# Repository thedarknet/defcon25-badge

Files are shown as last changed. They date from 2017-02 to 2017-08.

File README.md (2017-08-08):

# defcon25-badge
Badge Related items for defcon 25

Assembly instructions are located here:

https://dcdark.net/2017/badge/index.html

-----
Installation of IDE:
Follow the following instructions (step by step):  

http://gnuarmeclipse.github.io/install/

	Notes: on Window's have gotten both Mars and Luna to work
	on linux i've only gotten luna to work (on ubuntu 16.04 LTS)

Once eclipse is set up here's what the debug config needs to look like, notes the 2 -f openocd scripts that must be configured.

For 2017 development we are using this nucleo board, while it is not the exact MCU we plan to use it is close and the one we want to use does not have a dev kit.

http://www.st.com/content/st_com/en/products/evaluation-tools/product-evaluation-tools/mcu-eval-tools/stm32-mcu-eval-tools/stm32-mcu-nucleo/nucleo-f302r8.html

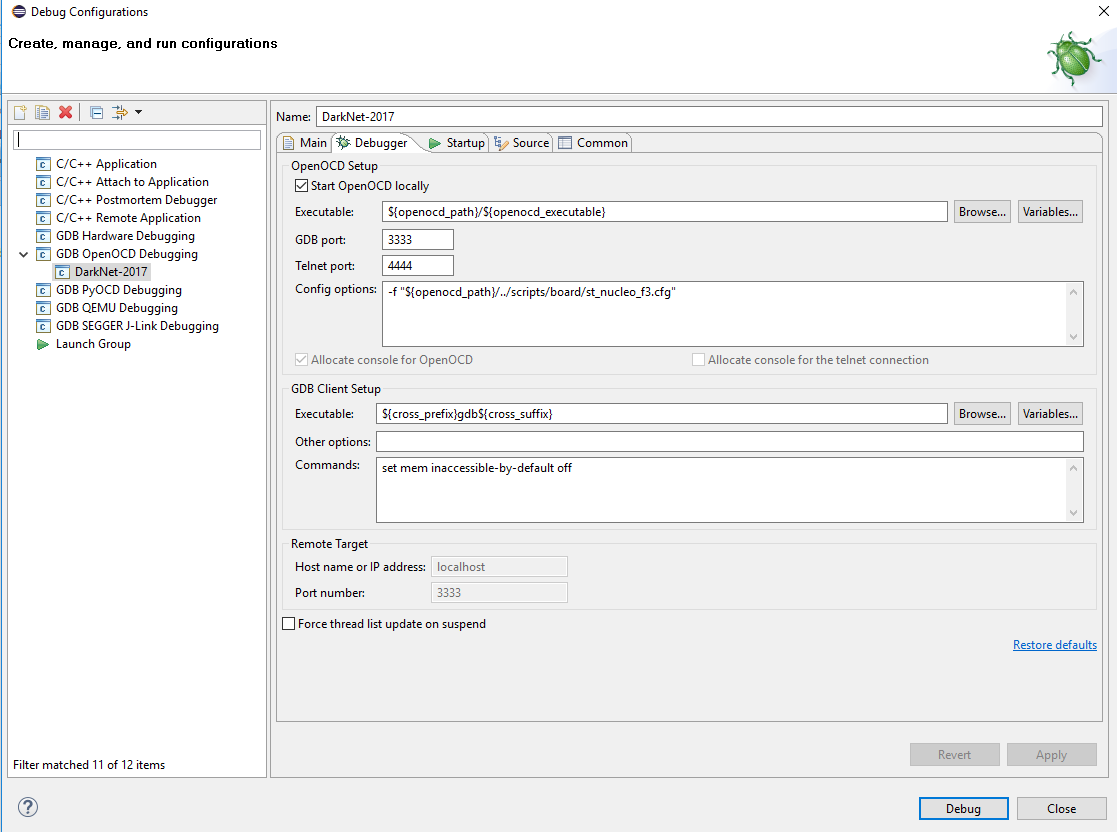
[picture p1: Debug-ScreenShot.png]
Debug Config


If you have the actual badge board you'll need debugging to look like this:

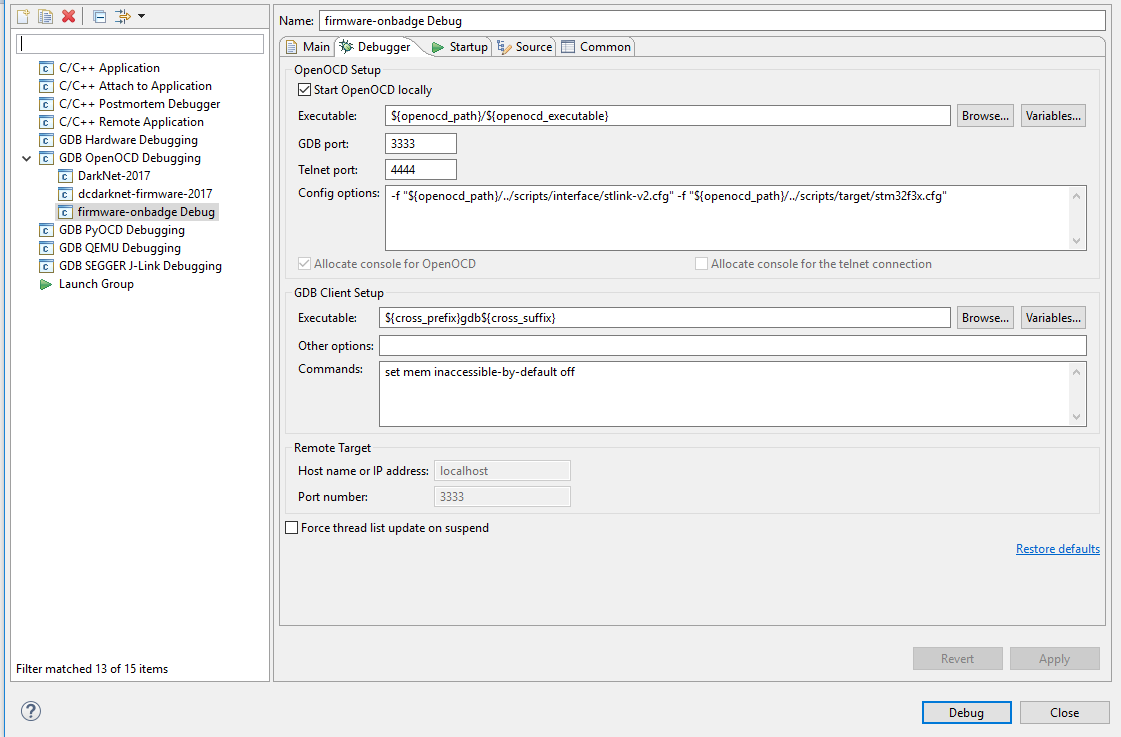
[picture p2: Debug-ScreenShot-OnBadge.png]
Debug Config


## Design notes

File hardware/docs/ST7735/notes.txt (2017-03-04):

SDA is infact: MOSI as the board is SPI not I2C

--https://webcache.googleusercontent.com/search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

https://github.com/XarkLabs/PDQ_GFX_Libs/blob/master/PDQ_ST7735/PDQ_ST7735.h line 513...that's the fastest avr can go but can the display go faster?

--1.44 seem to actually be IL19163C (not st7735)
https://luigidifraia.wordpress.com/2016/02/19/lcd-display-panels-casting-some-light-on-the-mess/
https://forum.pjrc.com/threads/25862-ILI9163C-128x128-TFT-driver
https://github.com/sumotoy/TFT_ILI9163C
http://www.ebay.co.uk/itm/111317541232?afsrc=1&rmvSB=true

https://forum.arduino.cc/index.php?topic=260605.135

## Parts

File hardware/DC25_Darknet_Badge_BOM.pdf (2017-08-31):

Part | Description | Vendor | Part number / link | Required Notes
Printed Circuit Board | OSH Park | https://oshpark.com/shared_projects/Shj2PfBl | 1 | Getting the boards made is one of the more expensive parts.
RFM69HCW 915Mhz +20dBm HopeRF Wireless Transceiver (RFM69HCW-915S2) | HopeRF | RFM69HCW-915S2 | 1
1.8 inch SPI Color TFT LCD Display ST7735S Module + Red PCB adapter | Amazon | B01LXWJ5O1 | 1 | A lot of places in China copy this module and sell it.
PkCell Lithium Polymer battery, LP803860 with JST connector | Adafruit | 2011 | 1 | We had these manufactured for the kit from PkCell, but Adafruit sells the same battery
JST Header PH Side 2 Pos 2MM | Digikey | 455-1719-ND | 1
SW1 | Apem Tactile Switches 7.8mm square tact | Mouser | MJTP1243 | 1
R24 | Xicon 270 Series 47 Ohm 1/8W Metal film resistor | Mouser | 270-47-RC | 1
LED11 | IR LED 940nm 100mA 210mW | Mouser | 782-TSAL6400 | 1
U3 | Vishay IR Receiver Module 2.5-5.5V 38kHz 45Deg 4000 bits/s | Digikey | TSOP2138 | 1 Wurth Electronics 2.54mm 4-pin Header | Mouser | 61300411121 | 1
| M3*14+6 Nylon Hex Standoff Spacer M3 Male x M3 Female 14mm | Amazon | SPC-NLB3MF/14-50 | 4 | You only need four, but the part is for a bag of 50
| M3 x 6mm Screws Nylon Round Head Phillips Drive Robot Light Bolts Plastic Black | Amazon | a16051100ux1000 | 4 | You only need four, but the part is for a bag of 100
| M3 Nylon Hex nuts Black | Amazon | a15070300ux0188 | 4 | You only need four, but the part is for a bag of 100
| .125"(3.2mm) x 12" x 12" Grey 2074 Acrylic Sheet | US Plastics | P-274 | 1
C1 | Multilayer Ceramic Capacitors MLCC - Johanson SMD/SMT 250volts 0.5pF ULTRA HIGH Q NPO | Mouser | 251R14S0R5BV4T | 1
C2 | Multilayer Ceramic Capacitors MLCC - Wurth Electronics SMD/SMT WCAP-CSGP 100000pF 0603 10% 10V MLCC | Mouser | 885012206020 | 1
C15 | Multilayer Ceramic Capacitors MLCC - Wurth Electronics SMD/SMT WCAP-CSGP 10000pF 0603 10% 16V MLCC | Mouser | 885012206040 | 1
C16 C17 C18 | Multilayer Ceramic Capacitors MLCC - AVX SMD/SMT 6.3V 4.7uF X5R 0603 20% Tol | Mouser | 06036D475MAT4A | 3
C19 C20 | Multilayer Ceramic Capacitors MLCC - AVX SMD/SMT 25V 47pF NP0 0603 10% Tol Auto | Mouser | 06033A470K4T2A | 2
C21 | Multilayer Ceramic Capacitors MLCC - Wurth Electronics SMD/SMT WCAP-CSGP1uF 0603 20% 10V MLCC | Mouser | 885012106010 | 1
C22 C23 C24 C25 | Multilayer Ceramic Capacitors MLCC - Wurth Electronics SMD/SMT WCAP-CSGP 47000pF 0603 10% 16V MLCC | Mouser | 885012206044 | 4
F1 | Bel Resettable Fuses - PPTC | Mouser | 0ZCJ0050FF2G | 1
L1 | Murata Ferrite Beads 0805 220 OHM | Mouser | BLM21PG221SN1D | 1
L2 | Bourns Fixed Inductors 10nH 5% MultiLayer High Frequency | Mouser | 652-CI160808-10NJ | 1
L3 | Bourns Fixed Inductors 4.7nH .3% MultiLayer High Frequency | Mouser | CI160808-4N7D | 1
LED12 LED13 | Lumex Standard LEDs - SMD Super Green, 565nm 2.2V, 20mcd | Mouser | SML-LX0603SGW-TR | 2
R1 thru R10 | Vishay Thick Film Resistors - SMD 1/4watt 47ohms 5% | Mouser | CRCW120647R0JNEA | 10
R11 thru R21 R31 R32 KOA Speer Thick Film Resistors - SMD 1/10W 5.1K OHM 5% | Mouser | RK73B1JTTDD512J | 13
R22 R30 R33 R34 R35 KOA Speer Thick Film Resistors - SMD 1/10W 2K OHM 5% | Mouser | RK73B1JTTDD202J | 5
R23 | Panasonic Thick Film Resistors - SMD 0603 470ohms 5% AEC-Q200 | Mouser | ERJ-3GEYJ471V | 1
R25 | Vishay Thick Film Resistors - SMD 1/10watt 10Kohms 1% | Mouser | CRCW060310K0FKEA | 1
R26 R27 | KOA Speer Thick Film Resistors - SMD 1/10W 27 OHM 5% | Mouser | RK73B1JTTDD270J | 2
R28 | KOA Speer Thick Film Resistors - SMD 1/10watts 68ohms 1% | Mouser | RK73H1JTTD68R0F | 1
| ARM Microcontrollers - STMicroelectronics MCU 32-Bit ARM Cortex M4 72MHz 128kB MCU FPU | Mouser | STM32F302RBT6 | 1
ANT | Johanson Antennas 915MHz ANTENNA | Mouser | 0915AT43A0026E | 1
U1 | ROHM Semiconductor LDO Voltage Regulators 1ch 500mA CMOS LDO Regulator | Mouser | BU33SD5WG-TR | 1
U2 | Microchip Battery Management Li-Ion/Li-Poly Charg Mgnt 4.5V Vreg out | Mouser | MCP73831T-5ACI/OT | 1
Y1 | Murata Resonators 8.000MHZ .5% CHIP RESONATOR | Mouser | CSTCE8M00G52-R0 | 1
LED1 thru LED10 | OSRAM LED YELLOW CLEAR 2SMD 222.5mcd 2V 20mA | Mouser | 720-LYT776Q2T126Z | 10 | Can be substituted with 720-LYT776S1T126Z

Note, this kit was designed to have most the surface mount parts assembled by pick and place. While it is

possible build the kit yourself, and solder everything by hand, it is more difficult than the kit sold at DEF CON.

However similar techniques can be used to hand solder, but extra parts should be ordered in anticipation of

small parts getting lost forever. To save on costs, I would also suggest working with other darknet agents to

do a group order and take advantage of price breaks.

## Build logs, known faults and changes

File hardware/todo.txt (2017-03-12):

TODO:
* schema:
* [DONE]: need to add sampling pins for touch to capacitor
* [DONE]: Remove capacitors from touch 
* [DONE]: add SD card NSS

4 layer ~$10 per board
2 layer ~5 per board

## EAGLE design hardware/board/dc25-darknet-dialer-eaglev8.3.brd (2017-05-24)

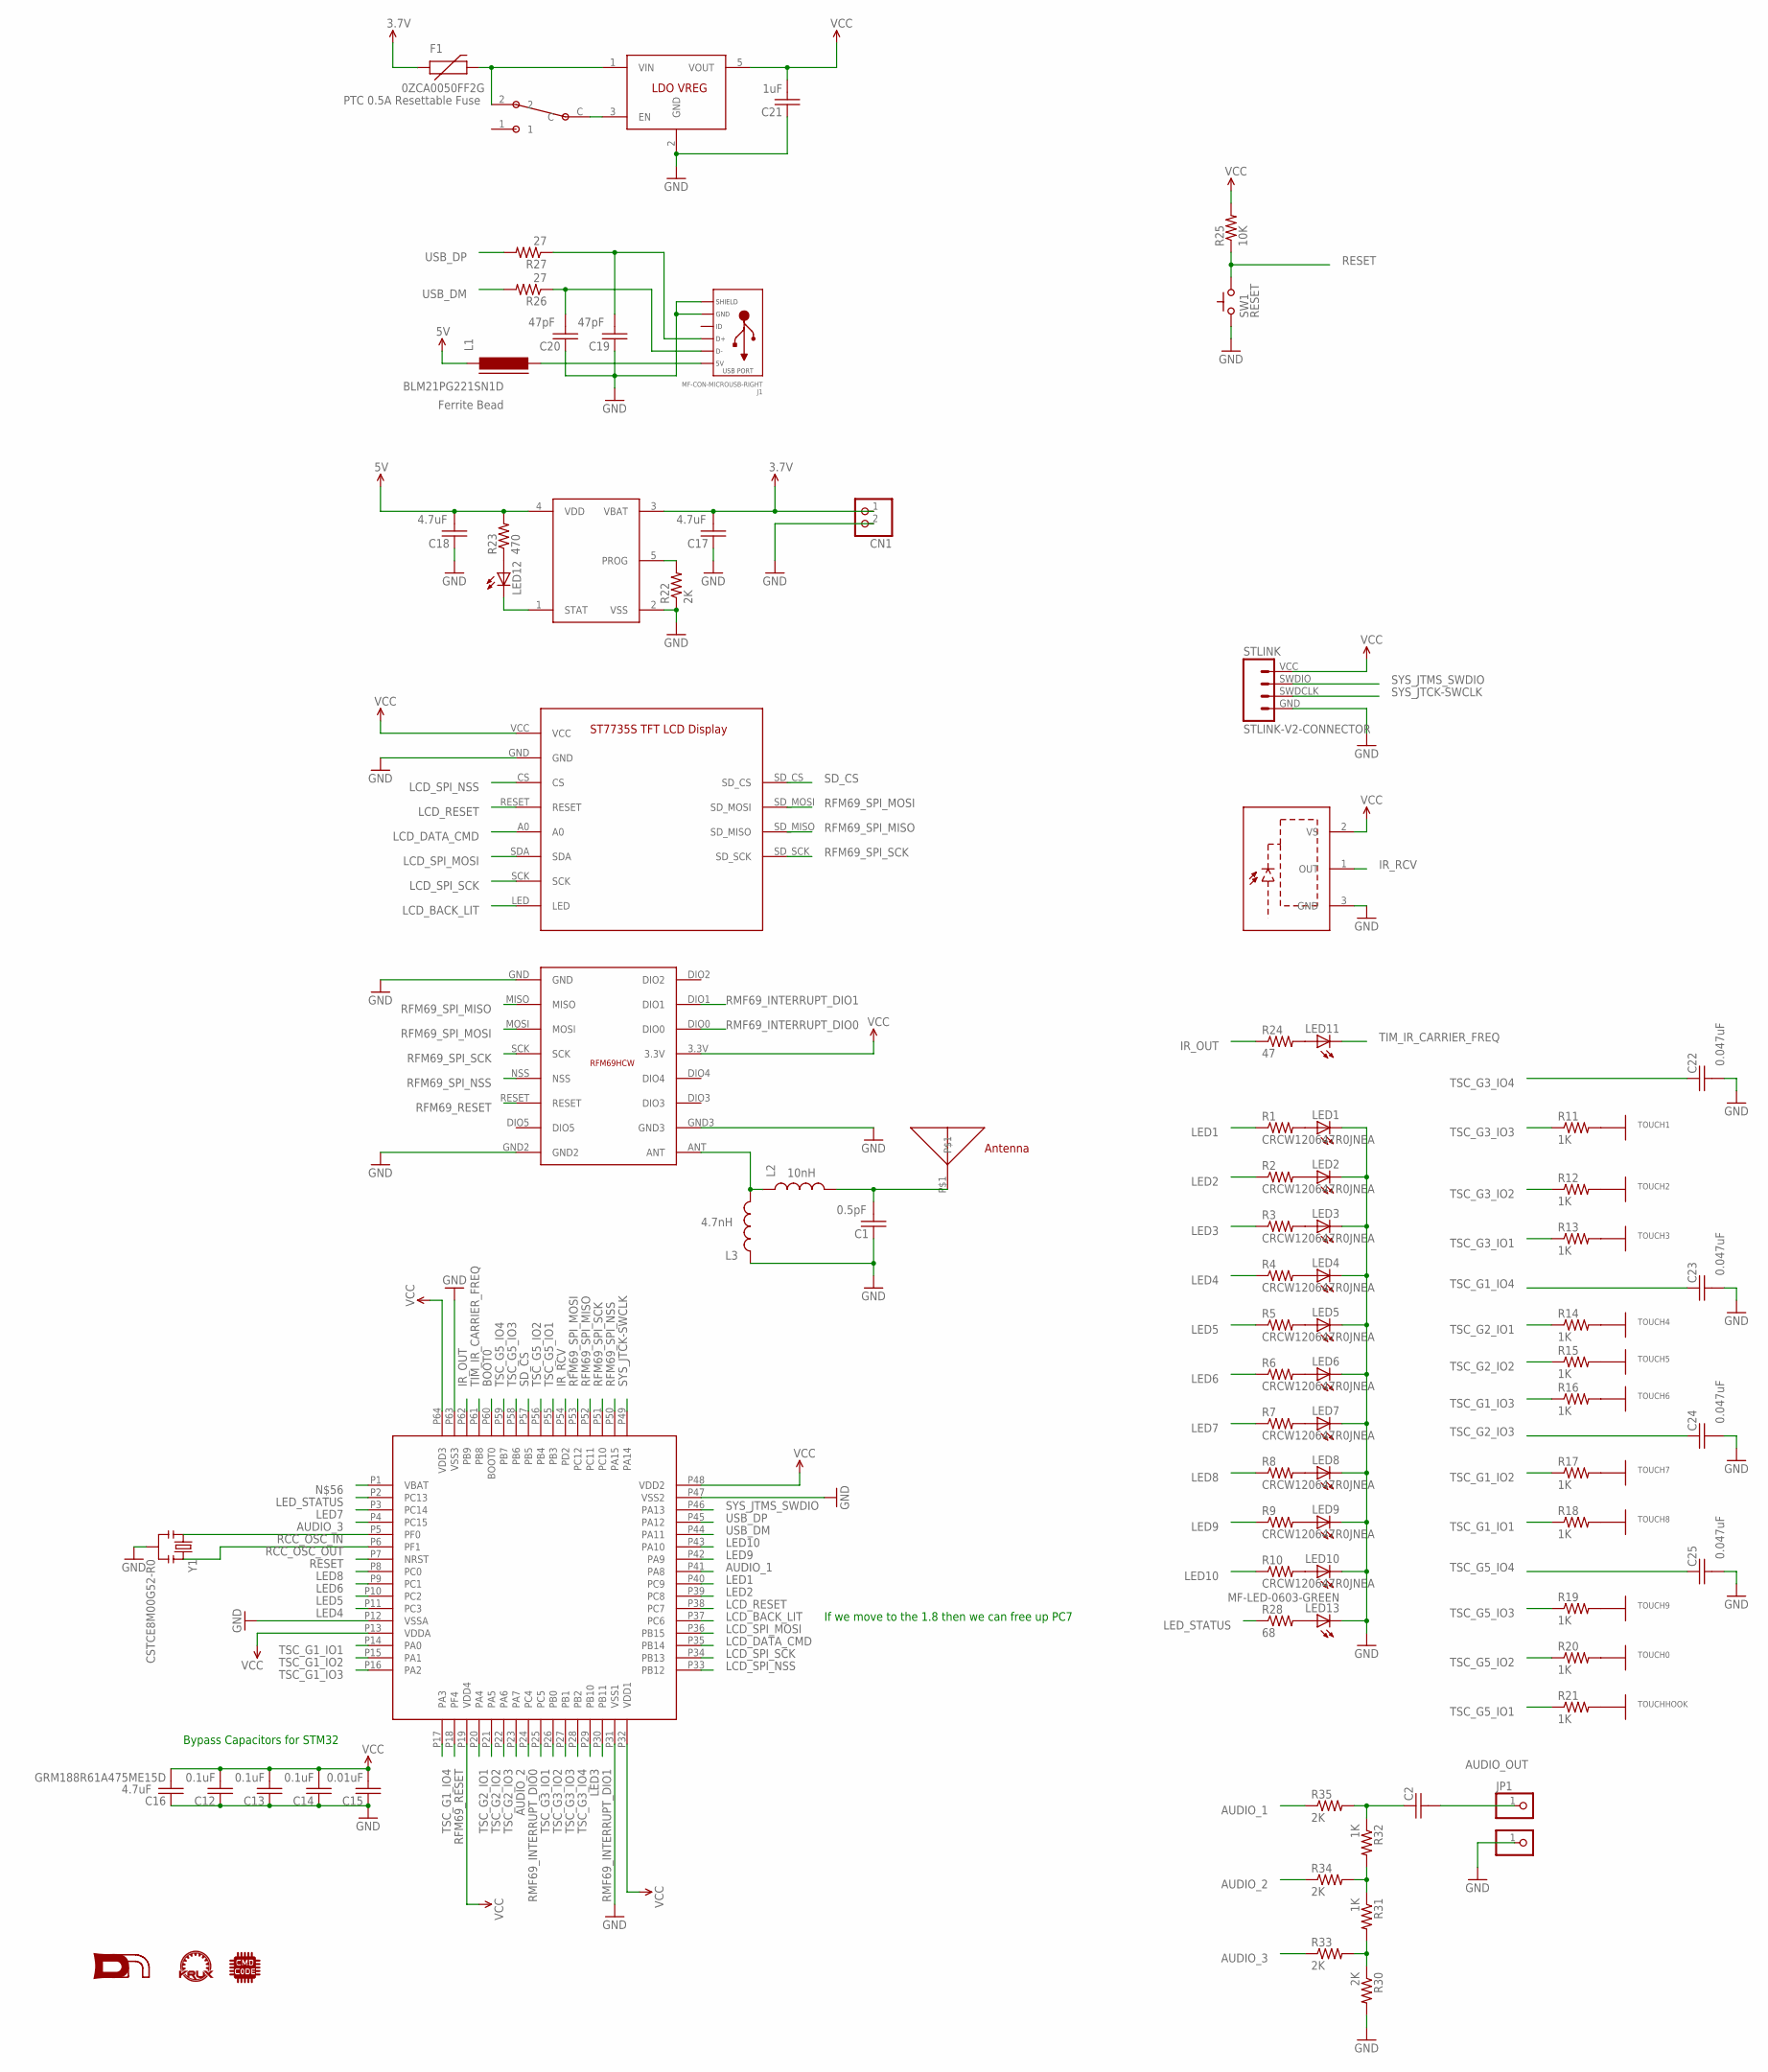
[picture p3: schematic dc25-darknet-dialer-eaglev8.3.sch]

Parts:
C1: 251R14S0R5BV4T; C0603
C2: GRM188C80G106ME47D; C0603
C12, C13, C14: 0.1uF; C0603
C15: 0.01uF; C0603
C16, C17, C18: GRM188R61A475ME15D; C0603
C19, C20: C0603C470J3GACTU; C0603
C21: 1uF; C0603
C22, C23, C24, C25: C0603C473J3RACAUTO; C0603
CN1: JST_2PIN-THM-RA; JST-PH-2-THM-RA
F1: 0ZCA0050FF2G; PTC-1206
J1: MF-CON-MICROUSB-RIGHT; MICROUSB-RIGHT
JP1, JP2: PINHD-1X1CB; 1X01-CLEANBIG
L1: BLM21PG221SN1D; FB603
L2: CI160808-10NJ; 0603
L3: CI160808-4N7D; 0603
LED1, LED2, LED3, LED4, LED5, LED6, LED7, LED8, LED9, LED10: LEDREVERSEMOUNT_NOPASTE; GULLWING_LED_NOPASTE
LED11: LED5MM
LED12, LED13: MF-LED-0603-GREEN; LED-0603
R1, R2, R3, R4, R5, R6, R7, R8, R9, R10: CRCW120647R0JNEA; 1206
R11, R12, R13, R14, R15, R16, R17, R18, R19, R20, R21, R31, R32: 1K; 0603-RES
R22, R30, R33, R34, R35: 2K; 0603-RES
R23: 470; 0603-RES
R24: 47; 0207/7
R25: 10K; 0603-RES
R26, R27: 27; 0603-RES
R28: 68; 0603-RES
STLINK: STLINK-V2-CONNECTOR; 1X04
SW1: RESET; TACTILE-2PIN-NARROW
TOUCH0: CAP_TOUCH0; CAP_TOUCH_PAD_0
TOUCH1: CAP_TOUCH1; CAP_TOUCH_PAD_1
TOUCH2: CAP_TOUCH2; CAP_TOUCH_PAD_2
TOUCH3: CAP_TOUCH3; CAP_TOUCH_PAD_3
TOUCH4: CAP_TOUCH4; CAP_TOUCH_PAD_4
TOUCH5: CAP_TOUCH5; CAP_TOUCH_PAD_5
TOUCH6: CAP_TOUCH6; CAP_TOUCH_PAD_6
TOUCH7: CAP_TOUCH7; CAP_TOUCH_PAD_7
TOUCH8: CAP_TOUCH8; CAP_TOUCH_PAD_8
TOUCH9: CAP_TOUCH9; CAP_TOUCH_PAD_9
TOUCHHOOK: CAP_TOUCHHOOK; CAP_TOUCH_PAD_HOOK
U1: BU33SD5WG-TR; SOT23-5
U2: MCP73831T-5ACI/OT; SOT23-5
U3: SOP22FLAT; IR-MODULE_FLAT
U$1: DN_LOGODC25; DARKNET_LOGO_DC25
U$2: STM32F302RBT6; LQFP64
U$11: SWITCH_SPDT; SPDT_SSAJ120100
U$12: KRUX_LOGO
U$15: RFM69HCWRFM69HCWSMDNOPASTE; 16PIN-PCB-SMD-NOPASTE
U$21: 0915AT43A0026E; CHIP_ANTENNA_1.8X8MM
U$22: ST7735S_LCD_MODULE; ST7735S_LCD_DISPLAY
U$23: CMD_C0DE_LOGO
Y1: CSTCE8M00G52-R0; RESONATOR-SMD

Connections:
ANT: L2.1, L3.2, U$15.ANT
AUDIO_1: R35.1, U$2.P41 (PA8)
AUDIO_2: R34.1, U$2.P23 (PA7)
AUDIO_3: R33.1, U$2.P4 (PC15)
AUDIO_OUT: C2.2, JP1.1
BOOT0: U$2.P60 (BOOT0)
GND: C1.1, C12.1, C13.1, C14.1, C15.1, C16.1, C17.1, C18.1, C19.1, C20.1, C21.1, C22.2, C23.2, C24.2, C25.2, CN1.2 (1), J1.5 (GND), J1.S1 (SLD), J1.S2 (SLD), J1.S3 (SLD), J1.S4 (SLD), J1.S5 (SLD), J1.S6 (SLD), JP2.1, L3.1, LED1.C, LED2.C, LED3.C, LED4.C, LED5.C, LED6.C, LED7.C, LED8.C, LED9.C, LED10.C, LED13.C, R22.1, R30.2, STLINK.GND, SW1.P$2 (C), U1.2 (GND), U2.2 (VSS), U3.3 (GND), U$2.P12 (VSSA), U$2.P31 (VSS1), U$2.P47 (VSS2), U$2.P63 (VSS3), U$15.GND, U$15.GND2, U$15.GND3, U$22.GND, Y1.2
IR_OUT: R24.1, U$2.P62 (PB9)
IR_RCV: U3.1 (OUT), U$2.P54 (PD2)
LCD_BACK_LIT: U$2.P37 (PC6), U$22.LED
LCD_DATA_CMD: U$2.P35 (PB14), U$22.A0
LCD_RESET: U$2.P38 (PC7), U$22.RESET
LCD_SPI_MOSI: U$2.P36 (PB15), U$22.SDA
LCD_SPI_NSS: U$2.P33 (PB12), U$22.CS
LCD_SPI_SCK: U$2.P34 (PB13), U$22.SCK
LED1: R1.1, U$2.P40 (PC9)
LED2: R2.1, U$2.P39 (PC8)
LED3: R3.1, U$2.P29 (PB10)
LED4: R4.1, U$2.P11 (PC3)
LED5: R5.1, U$2.P10 (PC2)
LED6: R6.1, U$2.P9 (PC1)
LED7: R7.1, U$2.P3 (PC14)
LED8: R8.1, U$2.P8 (PC0)
LED9: R9.1, U$2.P42 (PA9)
LED10: R10.1, U$2.P43 (PA10)
LED_STATUS: R28.1, U$2.P2 (PC13)
unnamed: R11.2, TOUCH1.PAD
unnamed: R12.2, TOUCH2.PAD
unnamed: R13.2, TOUCH3.PAD
unnamed: R14.2, TOUCH4.PAD
unnamed: R15.2, TOUCH5.PAD
unnamed: R16.2, TOUCH6.PAD
unnamed: R17.2, TOUCH7.PAD
unnamed: R18.2, TOUCH8.PAD
unnamed: R19.2, TOUCH9.PAD
unnamed: R20.2, TOUCH0.PAD
unnamed: R21.2, TOUCHHOOK.P$1
unnamed: LED1.A, R1.2
unnamed: LED2.A, R2.2
unnamed: LED3.A, R3.2
unnamed: LED4.A, R4.2
unnamed: LED5.A, R5.2
unnamed: LED6.A, R6.2
unnamed: LED7.A, R7.2
unnamed: LED8.A, R8.2
unnamed: LED9.A, R9.2
unnamed: LED10.A, R10.2
unnamed: R22.2, U2.5 (PROG)
unnamed: LED11.A, R24.2
unnamed: LED12.A, R23.1
unnamed: LED12.C, U2.1 (STAT)
unnamed: C19.2, J1.3 (D+), R27.1
unnamed: C20.2, J1.2 (D-), R26.1
unnamed: J1.1 (5V), L1.2
unnamed: LED13.A, R28.2
unnamed: F1.2, U1.1 (VIN), U$11.2
unnamed: C1.2, L2.2, U$21.P$1
unnamed: U1.3 (EN), U$11.C
unnamed: C2.1, R32.1, R35.2
unnamed: R31.1, R32.2, R34.2
unnamed: R30.1, R31.2, R33.2
RCC_OSC_IN: U$2.P5 (PF0), Y1.1
RCC_OSC_OUT: U$2.P6 (PF1), Y1.3
RESET: R25.1, SW1.P$1 (A), U$2.P7 (NRST)
RFM69_RESET: U$2.P18 (PF4), U$15.RESET
RFM69_SPI_MISO: U$2.P52 (PC11), U$15.MISO, U$22.SD_MISO
RFM69_SPI_MOSI: U$2.P53 (PC12), U$15.MOSI, U$22.SD_MOSI
RFM69_SPI_NSS: U$2.P50 (PA15), U$15.NSS
RFM69_SPI_SCK: U$2.P51 (PC10), U$15.SCK, U$22.SD_SCK
RMF69_INTERRUPT_DIO0: U$2.P24 (PC4), U$15.DIO0
RMF69_INTERRUPT_DIO1: U$2.P30 (PB11), U$15.DIO1
SD_CS: U$2.P57 (PB5), U$22.SD_CS
SYS_JTCK-SWCLK: STLINK.SWDCLK, U$2.P49 (PA14)
SYS_JTMS_SWDIO: STLINK.SWDIO, U$2.P46 (PA13)
TIM_IR_CARRIER_FREQ: LED11.K (C), U$2.P61 (PB8)
TSC_G1_IO1: R18.1, U$2.P14 (PA0)
TSC_G1_IO2: R17.1, U$2.P15 (PA1)
TSC_G1_IO3: R16.1, U$2.P16 (PA2)
TSC_G1_IO4: C23.1, U$2.P17 (PA3)
TSC_G2_IO1: R14.1, U$2.P20 (PA4)
TSC_G2_IO2: R15.1, U$2.P21 (PA5)
TSC_G2_IO3: C24.1, U$2.P22 (PA6)
TSC_G3_IO1: R13.1, U$2.P25 (PC5)
TSC_G3_IO2: R12.1, U$2.P26 (PB0)
TSC_G3_IO3: R11.1, U$2.P27 (PB1)
TSC_G3_IO4: C22.1, U$2.P28 (PB2)
TSC_G5_IO1: R21.1, U$2.P55 (PB3)
TSC_G5_IO2: R20.1, U$2.P56 (PB4)
TSC_G5_IO3: R19.1, U$2.P58 (PB6)
TSC_G5_IO4: C25.1, U$2.P59 (PB7)
USB_DM: R26.2, U$2.P44 (PA11)
USB_DP: R27.2, U$2.P45 (PA12)
VCC: C12.2, C13.2, C14.2, C15.2, C16.2, C21.2, R25.2, STLINK.VCC, U1.5 (VOUT), U3.2 (VS), U$2.P13 (VDDA), U$2.P19 (VDD4), U$2.P32 (VDD1), U$2.P48 (VDD2), U$2.P64 (VDD3), U$15.3.3V, U$22.VCC
VCC0: C18.2, L1.1, R23.2, U2.4 (VDD)
VCC1: C17.2, CN1.1 (2), F1.1, U2.3 (VBAT)

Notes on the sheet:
If we move to the 1.8 then we can free up PC7
Bypass Capacitors for STM32
0.5pF
4.7uF
47pF
0.047uF
PTC 0.5A Resettable Fuse
Ferrite Bead
10nH
4.7nH

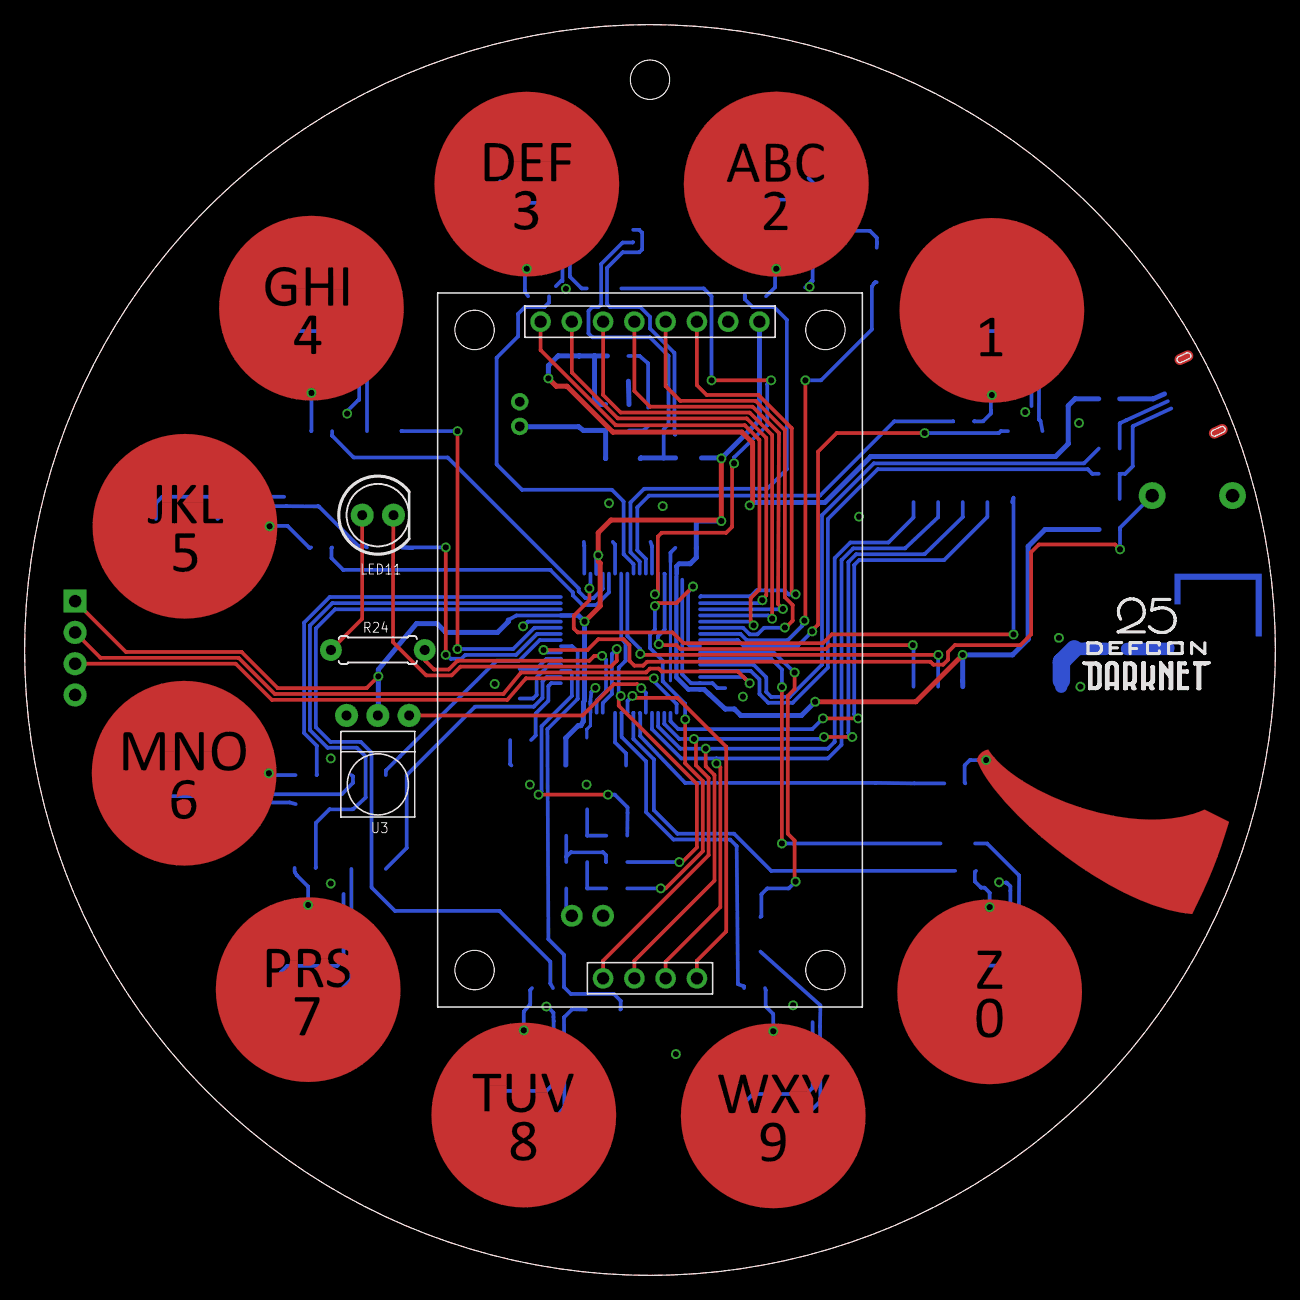
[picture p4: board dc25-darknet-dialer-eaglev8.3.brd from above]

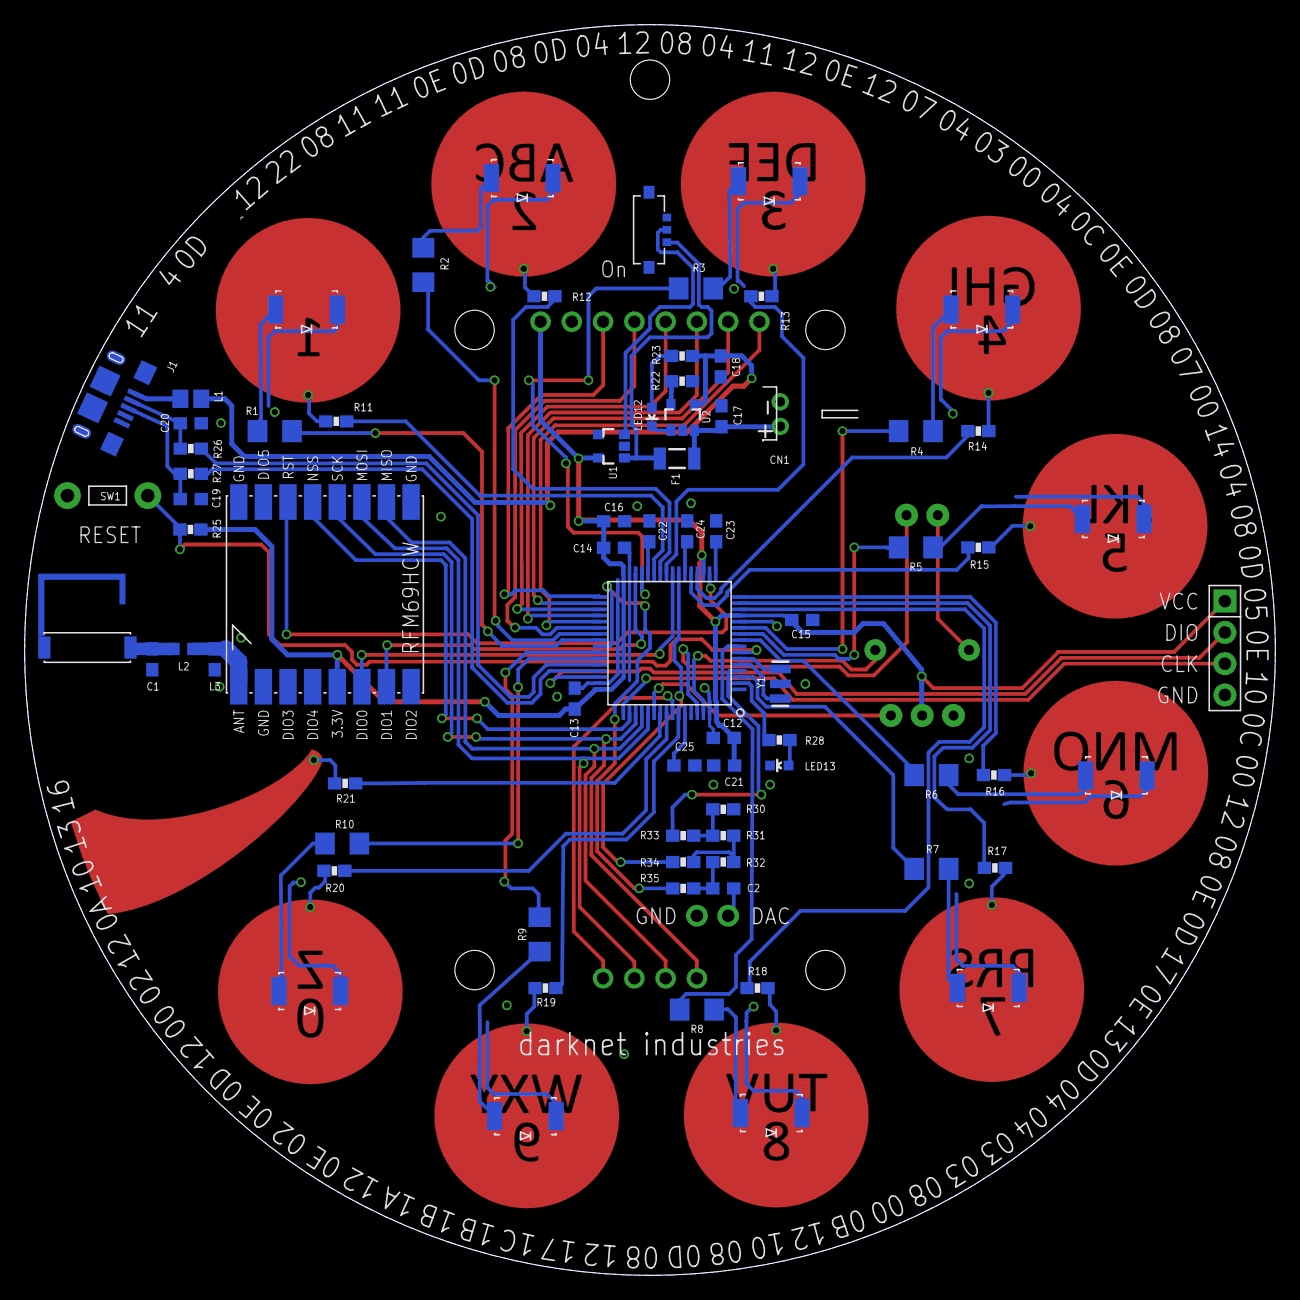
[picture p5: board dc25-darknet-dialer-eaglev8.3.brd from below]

Board: 2 copper layers, 101.6 x 101.6 mm, 96 parts (78 on the bottom side), 94 nets.

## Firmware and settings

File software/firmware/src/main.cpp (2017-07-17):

/**
 ******************************************************************************
 * File Name          : main.c
 * Description        : Main program body
 ******************************************************************************
 *
 * Copyright (c) 2017 STMicroelectronics International N.V.
 * All rights reserved.
 *
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
 ******************************************************************************
 */
/* Includes ------------------------------------------------------------------*/
#include "main.h"
#include "stm32f3xx_hal.h"
#include "dma.h"
#include "spi.h"
#include "tim.h"
#include "tsc.h"
#include "usb_device.h"
#include "gpio.h"

/* USER CODE BEGIN Includes */
#include "badge/dcdarknet_app.h"
#include "badge/logger.h"
#include "badge/ir.h"

/* USER CODE END Includes */


/* USER CODE BEGIN PV */
DCDarkNetApp DCDarkNet;
darknet::STM32Logger stm32DLogger(darknet::LOG_DEBUG_LEVEL);
darknet::STM32Logger stm32ILogger(darknet::LOG_INFO_LEVEL);
darknet::STM32Logger stm32ELogger(darknet::LOG_ERROR_LEVEL);

/* USER CODE END PV */

void SystemClock_Config(void);
void Error_Handler(void);

/* USER CODE BEGIN PFP */

/* USER CODE END PFP */

int main(void) {

	/* USER CODE BEGIN 1 */
	darknet::LogManager::get().addLogger(darknet::DEBUG_LOGGER_ID, &stm32DLogger);
	darknet::LogManager::get().addLogger(darknet::INFO_LOGGER_ID, &stm32ILogger);
	darknet::LogManager::get().addLogger(darknet::ERROR_LOGGER_ID, &stm32ELogger);
	/* USER CODE END 1 */

	/* MCU Configuration----------------------------------------------------------*/

	/* Reset of all peripherals, Initializes the Flash interface and the Systick. */
	HAL_Init();

	/* Configure the system clock */
	SystemClock_Config();

	/* Initialize all configured peripherals */
	MX_GPIO_Init();
	MX_DMA_Init();
	MX_SPI2_Init();
	MX_TIM16_Init();
	MX_TSC_Init();
	//MX_USB_DEVICE_Init();
	//comment if working on dev board
	MX_SPI3_Init();
	IRInit();

#if 0
	uint32_t t = 0;
	IRStartRx();
	while (t==0) {
		t = IRBytesAvailable();
	}
	//IRStartRx();
	char *p = (char *)IRGetBuff();
	INFOMSG(p);
#elif 0
	uint8_t b[5] = {0};
	IRTxBuff(&b[0],5);
#endif

	/* USER CODE BEGIN 2 */
	uint32_t initRet = DCDarkNet.init();
	if ((initRet & DCDarkNetApp::COMPONENTS_ITEMS::LCD) == 0) {
		// LCD did not initialize so we'll let the agent know via LED
		while (1) {
			HAL_GPIO_WritePin(LED_STATUS_GPIO_Port, LED_STATUS_Pin, GPIO_PIN_SET);
			HAL_Delay(200);
			HAL_GPIO_WritePin(LED_STATUS_GPIO_Port, LED_STATUS_Pin, GPIO_PIN_RESET);
			HAL_Delay(400);
		}
	}
	/* USER CODE END 2 */

	/* Infinite loop */
	/* USER CODE BEGIN WHILE */
	while (1) {
		/* USER CODE END WHILE */
		DCDarkNet.run();
		/* USER CODE BEGIN 3 */

	}
	/* USER CODE END 3 */

}

/** System Clock Configuration
 */
void SystemClock_Config(void) {

	RCC_OscInitTypeDef RCC_OscInitStruct;
	RCC_ClkInitTypeDef RCC_ClkInitStruct;
	RCC_PeriphCLKInitTypeDef PeriphClkInit;

	/**Initializes the CPU, AHB and APB busses clocks
	 */
	RCC_OscInitStruct.OscillatorType = RCC_OSCILLATORTYPE_HSE;
	RCC_OscInitStruct.HSEState = RCC_HSE_ON;
	RCC_OscInitStruct.HSEPredivValue = RCC_HSE_PREDIV_DIV1;
	RCC_OscInitStruct.PLL.PLLState = RCC_PLL_ON;
	RCC_OscInitStruct.PLL.PLLSource = RCC_PLLSOURCE_HSE;
	RCC_OscInitStruct.PLL.PLLMUL = RCC_PLL_MUL6;
	if (HAL_RCC_OscConfig(&RCC_OscInitStruct) != HAL_OK) {
		Error_Handler();
	}

	/**Initializes the CPU, AHB and APB busses clocks
	 */
	RCC_ClkInitStruct.ClockType = RCC_CLOCKTYPE_HCLK | RCC_CLOCKTYPE_SYSCLK | RCC_CLOCKTYPE_PCLK1 | RCC_CLOCKTYPE_PCLK2;
	RCC_ClkInitStruct.SYSCLKSource = RCC_SYSCLKSOURCE_PLLCLK;
	RCC_ClkInitStruct.AHBCLKDivider = RCC_SYSCLK_DIV1;
	RCC_ClkInitStruct.APB1CLKDivider = RCC_HCLK_DIV2;
	RCC_ClkInitStruct.APB2CLKDivider = RCC_HCLK_DIV1;

	if (HAL_RCC_ClockConfig(&RCC_ClkInitStruct, FLASH_LATENCY_1) != HAL_OK) {
		Error_Handler();
	}

	PeriphClkInit.PeriphClockSelection = RCC_PERIPHCLK_USB;
	PeriphClkInit.USBClockSelection = RCC_USBCLKSOURCE_PLL;
	if (HAL_RCCEx_PeriphCLKConfig(&PeriphClkInit) != HAL_OK) {
		Error_Handler();
	}

	/**Configure the Systick interrupt time
	 */
	HAL_SYSTICK_Config(HAL_RCC_GetHCLKFreq() / 1000);

	/**Configure the Systick
	 */
	HAL_SYSTICK_CLKSourceConfig(SYSTICK_CLKSOURCE_HCLK);

	/* SysTick_IRQn interrupt configuration */
	HAL_NVIC_SetPriority(SysTick_IRQn, 0, 0);
}

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


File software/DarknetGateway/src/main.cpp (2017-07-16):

#include "RPIHardware.h"
#include "RFM69.h"
#include <cstdio>
#include <signal.h>
#include <curl/curl.h>
#include <cstring>
#include <tbb/include/tbb/concurrent_queue.h>
#include <tbb/include/tbb/task_scheduler_init.h>
#include <tbb/include/tbb/task.h>

volatile sig_atomic_t force_exit = false;

#define CS_PIN  RPI_V2_GPIO_P1_37 // Slave Select on GPIO26  so P1 connector pin #37
#define IRQ_PIN RPI_V2_GPIO_P1_16 // IRQ on GPIO23 so P1 connector pin #16
#define RST_PIN RPI_V2_GPIO_P1_33 // reset on GPIO13 so P1 connector pin #33

RPISPI RPISPI1(0,CS_PIN);
RPIHardware Device(&RPISPI1,0);

Hardware &Hardware::get() {
	return Device;
}

void sig_handler(int sig) {
  printf("\n%d Break received, exiting!\n", sig);
  force_exit=true;
}

class WorkItem;
size_t handleCurl(void *ptr, size_t size, size_t nmemb, WorkItem *hcd);


#define MAX_DATA_LEN 62
class  WorkItem {
protected:
	enum COMMAND {
		GET_REP = 0xFF12
		, EPICS_COMPLETED = 0xFF13
		, RANDOM = 0xFF14
	};
public:
	WorkItem(const uint8_t *d, uint8_t dataSize, uint16_t sid, int16_t rssi)
		: MsgSize(dataSize), SenderID(sid), RSSI(rssi), RS() {
		memcpy(&Data[0],d,dataSize);
	}
	bool isValid() {
		if(MsgSize>3) {
			RS.Command = *((int*)&Data[0]);
			switch(RS.Command) {
			case GET_REP: EPICS_COMPLETED:
				return true;
				break;
			}
		}
		return false;
	}
	bool doWork() {
		switch(RS.Command) {
			case GET_REP: 
					RS.RetVal1 = 10;	
				break;
			case EPICS_COMPLETED:
					RS.RetVal1 = 100;	
				break;
		}
#if 0
		HandledCurlData handledCurlData(0);
		CURL *hnd = curl_easy_init();
		curl_easy_setopt(hnd, CURLOPT_CUSTOMREQUEST, "POST");
		curl_easy_setopt(hnd, CURLOPT_URL, "https://echo.getpostman.com/post");
		curl_easy_setopt(hnd, CURLOPT_WRITEFUNCTION, handleCurl);
		curl_easy_setopt(hnd, CURLOPT_WRITEDATA, &handledCurlData);
 
		struct curl_slist *headers = NULL;
		headers = curl_slist_append(headers, "postman-token: 62c5f82f-64e3-0407-e673-7d26ed68e109");
		headers = curl_slist_append(headers, "cache-control: no-cache");
		headers = curl_slist_append(headers, "content-type: text/plain");
		curl_easy_setopt(hnd, CURLOPT_HTTPHEADER, headers);
		curl_easy_setopt(hnd, CURLOPT_POSTFIELDS, "Duis posuere volutpat.");
		CURLcode ret = curl_easy_perform(hnd);
		curl_easy_cleanup(hnd);
#endif
		RS.Success=1;
		return RS.Success;
	}
	void *getResultBuffer() {
		return &RS;
	}
	uint32_t getResultSize() {
		return sizeof(RS);
	}

	uint16_t getSender() {
		return SenderID;
	}
	
	struct ResponseStruct {
		uint32_t Command;
		uint8_t  Success;
		uint32_t RetVal1;
		ResponseStruct() : Command(0), Success(0), RetVal1(0) {}
	} __attribute__((packed));

	void processResponse(const char *p, size_t size) {
		sscanf(p,"%u",&RS.RetVal1);
		RS.Success=1;
	}
private:
	//request data
	uint8_t Data[MAX_DATA_LEN];
	uint8_t MsgSize;
	uint16_t SenderID;
	int16_t RSSI;
	//response data
	ResponseStruct RS;
};

size_t handleCurl(void *ptr, size_t size, size_t nmemb, WorkItem *hcd) {
	hcd->processResponse((const char *)ptr,size*nmemb);
	return size*nmemb;
}

tbb::concurrent_queue<WorkItem*> OutGoingWorkQueue;

class WorkTask : public tbb::task {
public:
	WorkTask(WorkItem *wi) : WI(wi) {}
	tbb::task *execute() {
		if(WI->doWork()) {
			OutGoingWorkQueue.push(WI);
		}
		return null;
	}
	virtual ~WorkTask() {}
private:
	WorkItem *WI;
};

int main(int arc, char *agrv[]) {
	signal(SIGINT, sig_handler);

	tbb::task_scheduler_init tsi;

	RPISPI1.init(SPI_1_3125MHZ,MSB,SPI_MODE0);
	RFM69 Radio(false,IRQ_PIN);
	bool b = Radio.initialize(RF69_915MHZ,0xFFFE,1);
	if(b) {
		Radio.readAllRegs();
		printf("RSSI:  %d \n", Radio.readRSSI());
		printf("Gain:  %d \n", Radio.getCurrentGain());
		printf("ImpedenceLevel:  %d \n", Radio.getImpedenceLevel());
		printf("RSSIThreshHold:  %d \n", Radio.getRSSIThreshHold());
	} else {
		printf("init failed\n");
	}

	curl_global_init(CURL_GLOBAL_ALL);
	while(!force_exit) {
		if(Radio.receiveDone()) {
			WorkItem *wi = new WorkItem((const uint8_t*)&Radio.DATA[0],Radio.DATALEN, Radio.SENDERID, Radio.RSSI);
			if(wi->isValid()) {
				WorkTask *wt = new WorkTask(wi);
				WorkTask::enqueue(*wt);
			}
		}
		WorkItem *wi = 0;
		int count=0;
		while(Radio.canSend() && count++<10 && OutGoingWorkQueue.try_pop(wi)) {
			Radio.send(wi->getSender(),wi->getResultBuffer(),wi->getResultSize());
			delete wi;
		}	
	}
	curl_global_cleanup();
	return 0;
}

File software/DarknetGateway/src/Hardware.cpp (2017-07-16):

// ArduinoCompat/HardwareSPI.cpp
//
// Interface between Arduino-like SPI interface and STM32F4 Discovery and similar
// using STM32F4xx_DSP_StdPeriph_Lib_V1.3.0


#include "Hardware.h"

ErrorType SPI::masterListen() {
	return onMasterListen();
}

ErrorType SPI::select() {
	return onSelect();
}

ErrorType SPI::unselect() {
	return onUnselect();
}

uint8_t SPI::transfer(uint8_t data) {
	return onTransfer(data);
}

bool SPI::init(SPIFrequency  divider, BitOrder  bitOrder, SPIMode dataMode) {
	return onInit(divider, bitOrder, dataMode);
}

bool SPI::shutdown() {
	return onShutdown();
}

SPI::~SPI() {

}


Hardware::Hardware(SPI *one, SPI *two) : SPI1(one), SPI2(two) {
}

ErrorType Hardware::enableIRQ() {
	return onEnableIRQ();
}

ErrorType Hardware::disableIRQ() {
	return onDisableIRQ();
}

ErrorType Hardware::attachInterrupt(int uniqueIRQ, void (*handler)(void), int mode) {
	return onAttachInterrupt(uniqueIRQ, handler, mode);
}

void Hardware::pinMode(uint8_t pin, PINMODE mode) {
	onPinMode(pin,mode);
}

void Hardware::digitalWrite(uint8_t pin, Hardware::PINVAL val) {
	onDigitalWrite(pin,val);
}

uint8_t Hardware::digitalRead(uint8_t pin) {
	return onDigitalRead(pin);
}

SPI *Hardware::getSPI1() {
	return SPI1;
}

SPI *Hardware::getSPI2() {
	return SPI2;
}

Hardware::~Hardware() {

}

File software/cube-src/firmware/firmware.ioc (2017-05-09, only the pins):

Mcu.UserName=STM32F302RBTx
PA0.Signal=TSC_G1_IO1
PA1.Signal=TSC_G1_IO2
PA10.GPIO_Label=LED10
PA10.Signal=GPIO_Output
PA11.Signal=USB_DM
PA12.Signal=USB_DP
PA13.Signal=SYS_JTMS-SWDIO
PA14.Signal=SYS_JTCK-SWCLK
PA15.GPIO_Label=RADIO_SPI3_NSS
PA15.Signal=SPI3_NSS
PA2.Signal=TSC_G1_IO3
PA3.Signal=TSC_G1_IO4
PA4.Signal=TSC_G2_IO1
PA5.Signal=TSC_G2_IO2
PA6.Signal=TSC_G2_IO3
PA7.GPIO_Label=AUDIO_2
PA7.Signal=GPIO_Output
PA8.GPIO_Label=AUDIO1
PA8.Signal=GPIO_Output
PA9.GPIO_Label=LED9
PA9.Signal=GPIO_Output
PB0.Signal=TSC_G3_IO2
PB1.Signal=TSC_G3_IO3
PB10.GPIO_Label=LED3
PB10.Signal=GPIO_Output
PB11.GPIO_Label=RADIO_INTERRUPT_DIO1_EXTI11
PB11.Signal=GPXTI11
PB12.GPIO_Label=LCD_CS
PB12.Signal=GPIO_Output
PB13.GPIO_Label=LCD_SPI2_SCK
PB13.Signal=SPI2_SCK
PB14.GPIO_Label=LCD_DATA_CMD
PB14.Signal=GPIO_Output
PB15.GPIO_Label=LCD_SPI2_MOSI
PB15.Signal=SPI2_MOSI
PB2.Signal=TSC_G3_IO4
PB3.Signal=TSC_G5_IO1
PB4.Signal=TSC_G5_IO2
PB5.GPIO_Label=SD_CARD_CS
PB5.Signal=GPIO_Output
PB6.Signal=TSC_G5_IO3
PB7.Signal=TSC_G5_IO4
PB8.GPIO_Label=TIM_IR_CARRIER_FREQ
PB8.Signal=S_TIM16_CH1
PB9.GPIO_Label=IR_TX
PB9.Signal=GPIO_Output
PC0.GPIO_Label=LED8
PC0.Signal=GPIO_Output
PC1.GPIO_Label=LED6
PC1.Signal=GPIO_Output
PC10.GPIO_Label=RADIO_SPI3_SCK
PC10.Signal=SPI3_SCK
PC11.GPIO_Label=RADIO_SPI3_MISO
PC11.Signal=SPI3_MISO
PC12.GPIO_Label=RADIO_SPI3_MOSI
PC12.Signal=SPI3_MOSI
PC13.GPIO_Label=LED_STATUS
PC13.Signal=GPIO_Output
PC14-OSC32_IN.GPIO_Label=LED7
PC14-OSC32_IN.Signal=GPIO_Output
PC15-OSC32_OUT.GPIO_Label=AUDIO3
PC15-OSC32_OUT.Signal=GPIO_Output
PC2.GPIO_Label=LED5
PC2.Signal=GPIO_Output
PC3.GPIO_Label=LED4
PC3.Signal=GPIO_Output
PC4.GPIO_Label=RADIO_INTERRUPT_DIO0_EXTI4
PC4.Signal=GPXTI4
PC5.Signal=TSC_G3_IO1
PC6.GPIO_Label=LCD_BACK_LIT
PC6.Signal=GPIO_Output
PC7.GPIO_Label=LCD_RESET
PC7.Signal=GPIO_Output
PC8.GPIO_Label=LED2
PC8.Signal=GPIO_Output
PC9.GPIO_Label=LED1
PC9.Signal=GPIO_Output
PD2.GPIO_Label=IR_RCV
PD2.Signal=GPXTI2
PF0-OSC_IN.Signal=RCC_OSC_IN
PF1-OSC_OUT.Signal=RCC_OSC_OUT
PF4.GPIO_Label=RFM69_RESET
PF4.Signal=GPIO_Output

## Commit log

2016-12-27 adding development board - dev board only has 64K flash rather than 128K
2016-12-27 chip we are planning on using is stm32f3CB not RB
2016-12-27 yes we are using the rb as that rb is the 64 pin version
2016-12-28 adding stm32cubemx file
2017-01-04 Added Eagle PCB files
    [dc25-darknet-dialer.brd, dc25-darknet-dialer.sch]
2017-01-04 added docs on the Li-Ion/Li-Po charge controller
2017-01-04 Updated board to include values for bypass caps
    [dc25-darknet-dialer.brd, dc25-darknet-dialer.sch]
2017-01-25 Routing and layout progress
    [dc25-darknet-dialer.brd, dc25-darknet-dialer.sch]
2017-01-26 Updated design
    [dc25-darknet-dialer.brd, dc25-darknet-dialer.sch]
2017-02-07 Added power and IR
    [dc25-darknet-dialer.brd, dc25-darknet-dialer.sch]
2017-02-07 Updated power, wired IR
    [dc25-darknet-dialer.brd, dc25-darknet-dialer.sch]
2017-02-08 Connected LEDs
    [dc25-darknet-dialer.brd, dc25-darknet-dialer.sch]
2017-02-08 Added resonator
    [dc25-darknet-dialer.brd, dc25-darknet-dialer.sch]
2017-02-08 DRC fixes
    [dc25-darknet-dialer.brd]
2017-02-09 Additional details on power, added fuse and prep for 3.3v LDO
    [dc25-darknet-dialer.brd, dc25-darknet-dialer.sch]
2017-02-12 updated png with debug for nucleo fixed file encoding for display_device
    [display_device.cpp]
2017-02-13 display now works, still need some code clean up and a pass to ensure we are handling the CS and data/cmd pins correctly
    [display_device.cpp, main.cpp]
2017-03-04 adding eagle version 8 files to ensure krux can open
    [dc25-darknet-dialer-eaglev8.brd, dc25-darknet-dialer-eaglev8.sch]
2017-03-05 added stlink connector to lbr moved radio spi from spi1 to spi3 to free up pins for touch sensening
    [dc25-darknet-dialer-eaglev8.brd, dc25-darknet-dialer-eaglev8.sch]
2017-03-08 moved parts onto board, but not in correct location yet
    [dc25-darknet-dialer-eaglev8.brd]
2017-03-12 updates to only have 1 pin for IR timer added todo list
    [dc25-darknet-dialer-eaglev8.brd, dc25-darknet-dialer-eaglev8.sch]
2017-03-12 added new part to library: SD_CARD_HEADER diff of todo.txt shows what else was completed on this check in. adding another doc on cap sense and updated stm32cube file
    [dc25-darknet-dialer-eaglev8.brd, dc25-darknet-dialer-eaglev8.sch]
2017-03-14 Cleanup and update of schematic, added voltage regulator
    [dc25-darknet-dialer-eaglev8.brd, dc25-darknet-dialer-eaglev8.sch]
2017-03-17 moving current firmware to a test directory so we can use it for 1 off tests
2017-03-19 Updated display module, added antenna design
    [dc25-darknet-dialer-eaglev8.brd, dc25-darknet-dialer-eaglev8.sch]
2017-03-19 Changed status LED for board debugging
    [dc25-darknet-dialer-eaglev8.brd, dc25-darknet-dialer-eaglev8.sch]
2017-03-20 Finished routing
    [dc25-darknet-dialer-eaglev8.brd, dc25-darknet-dialer-eaglev8.sch]
2017-03-21 Changed orientation of IR reciver
    [dc25-darknet-dialer-eaglev8.brd, dc25-darknet-dialer-eaglev8.sch]
2017-03-21 Updated silk screen parts indicators
    [dc25-darknet-dialer-eaglev8.brd, dc25-darknet-dialer-eaglev8.sch]
2017-03-23 Updated parts for upload to MacroFab
    [dc25-darknet-dialer-eaglev8.brd, dc25-darknet-dialer-eaglev8.sch]
2017-04-17 Changed USB connector to Macrofab eagle library
    [dc25-darknet-dialer-eaglev8.brd, dc25-darknet-dialer-eaglev8.sch]
2017-04-17 Added on/off switch
    [dc25-darknet-dialer-eaglev8.brd, dc25-darknet-dialer-eaglev8.sch]
2017-04-24 Minor tweaks
    [dc25-darknet-dialer-eaglev8.brd]
2017-04-24 added 3-bit DAC circuit
    [dc25-darknet-dialer-eaglev8.1.brd, dc25-darknet-dialer-eaglev8.1.sch]
2017-04-24 Added audio out pads
    [dc25-darknet-dialer-eaglev8.1.brd, dc25-darknet-dialer-eaglev8.1.sch]
2017-04-27 added code to test leds
2017-04-30 updated pin definition to support Audio pins
2017-04-30 updated linker script to use all memory (as the dev board was smaller in flash and ram)
2017-05-03 Updated switch hook, and removed solder paste for kit parts
    [dc25-darknet-dialer-eaglev8.1.brd, dc25-darknet-dialer-eaglev8.1.sch]
2017-05-05 game of life actually works correctly but only 32 columns...
    [GameOfLife.cpp, menus.cpp]
2017-05-07 closer to a working IR IRQ's where configured wrong, clock was configured wrong
    [firmware.ioc]
2017-05-08 added puzzle silk screen
    [dc25-darknet-dialer-eaglev8.2.brd, dc25-darknet-dialer-eaglev8.2.sch]
2017-05-09 Fixed puzzle silk screen, minor ground fill tweaks
    [dc25-darknet-dialer-eaglev8.2.brd]
2017-05-09 Moved the radio board over a little to give more room to solder.
    [dc25-darknet-dialer-eaglev8.2.brd]
2017-05-10 moved resistor silk screen
    [dc25-darknet-dialer-eaglev8.2.brd]
2017-05-14 fixed a bunch of small visual bugs
    [dcdarknet_app.cpp, irmenu.cpp]
2017-05-15 fixed a number of small display bugs
    [gui.cpp]
2017-05-23 updated schematic to populate audio
    [dc25-darknet-dialer-eaglev8.2.brd, dc25-darknet-dialer-eaglev8.2.sch]
2017-05-23 Helps if one saves
    [dc25-darknet-dialer-eaglev8.2.brd, dc25-darknet-dialer-eaglev8.2.sch]
2017-05-24 Updated library for new logo
    [dc25-darknet-dialer-eaglev8.2.brd, dc25-darknet-dialer-eaglev8.2.sch]
2017-05-24 added revision 3 of the board
    [dc25-darknet-dialer-eaglev8.3.brd, dc25-darknet-dialer-eaglev8.3.sch]
2017-05-24 Fixed spacing around switch hook
    [dc25-darknet-dialer-eaglev8.3.brd, dc25-darknet-dialer-eaglev8.3.sch]
2017-06-02 new framebuffer no buffer class working
2017-06-02 keyboard test now prints in the right location
2017-06-02 fixed a bug with saving screen saver time colors render right with new optimzed renderer
    [KeyStore.cpp, dcdarknet_app.cpp, display_device.cpp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]
2017-06-18 dialer leds working
2017-06-18 Now led under pad selection lights up.
2017-07-13 fixed a few smaller bugs
    [dcdarknet_app.cpp, menus.cpp]
2017-07-16 threading added
2017-07-17 removing usb and fixes to draw image
    [display_device.cpp]
2017-07-17 fixed line of code that excited compiler bug turned off boot image when debugging to save space
    [dcdarknet_app.cpp]
2017-07-22 fixed bug with slow rendering on set agent name screen
    [menus.cpp]
2017-07-22 fixed clear screen bug on entering 3d we now start on the menu screen again
    [dcdarknet_app.cpp]
2017-07-30 fixed bug with dialer
    [menus.cpp]
2017-08-08 Update README.md
    Added link to the assembly instructions
2017-08-31 Added Bill of Materials
2018-03-09 fixed the darknet message not being received if screen saver or 3d mode is running
    [GameOfLife.cpp, dcdarknet_app.cpp, menus.cpp]

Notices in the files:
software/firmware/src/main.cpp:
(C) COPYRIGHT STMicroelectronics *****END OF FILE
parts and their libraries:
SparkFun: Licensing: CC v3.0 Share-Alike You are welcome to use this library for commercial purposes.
